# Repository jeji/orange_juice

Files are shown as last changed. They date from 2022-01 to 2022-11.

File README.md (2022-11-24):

# 我的频道 My Channel 
youtube: https://www.youtube.com/channel/UChTFW-Y9eg54AaTY_yama7A \
bilibili：https://b23.tv/pqzW2up

# 版本信息 Release Note
2022/10/09: v0.8 Reverse the polarity to match the common wire setup \
2022/02/06: v0.7 bate release version, passed function and stable test

**[香橙派Zero2版本](https://github.com/jeji/orange_juice_2)** \
**[Version for Orange Pi Zero2](https://github.com/jeji/orange_juice_2)** \

TODO:
- Integrate CAN controller/receivier
- Add motor driver socket as an universal socket for other feature, like: 
   - PWM controlled open loop buck convert for better fan noise 
   - Voron design MAX31865
   - Other SPI/UART/GPIO device

# 开始之前 Before You Start 
- 我并不是专业的电子工程师，设计本项目只是为了好玩和方便DIY Voron 3D打印机
- 你将自行承担由此带来的所有风险
- 社区有诸多反馈香橙派zero的CPU温度过高，所以在使用中请加强散热
- 本项目为基于GPL3.0的开源项目，欢迎魔改。如果你有更好的改进也请务必与我分享 
- **(!) 请特别注意文章中加粗和带"(!)"部分的内容**

- I'm not prefesstional electronic engineer, I designed this for fun and convenience while DIY my Voron printer
- You will take it as your own risk for any potential damages
- Overheat issue is being reported for OrangePi Zero H2+ CPU, hence a proper cooling fan even with cooling fin is strongly recommended
- This project is based GPL3.0 license, you are free to modify it to yourown version. Please do share the joy with me if you did that
- **(!) Please pay attention for the bold and with "(!)" content**

# 代号：橙汁 BoardName：Orange Juice

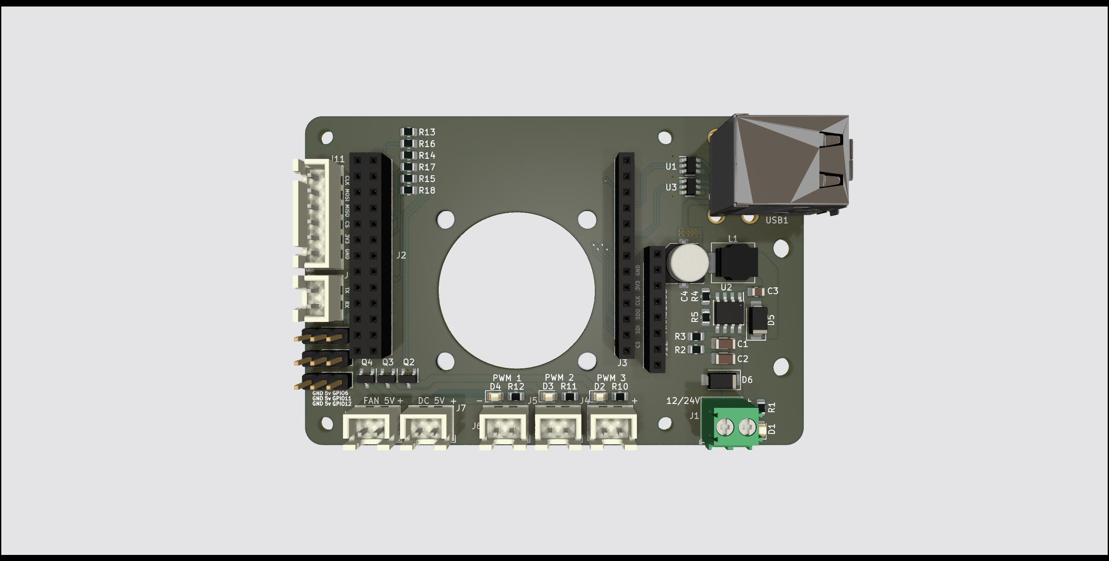
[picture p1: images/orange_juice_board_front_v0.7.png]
  

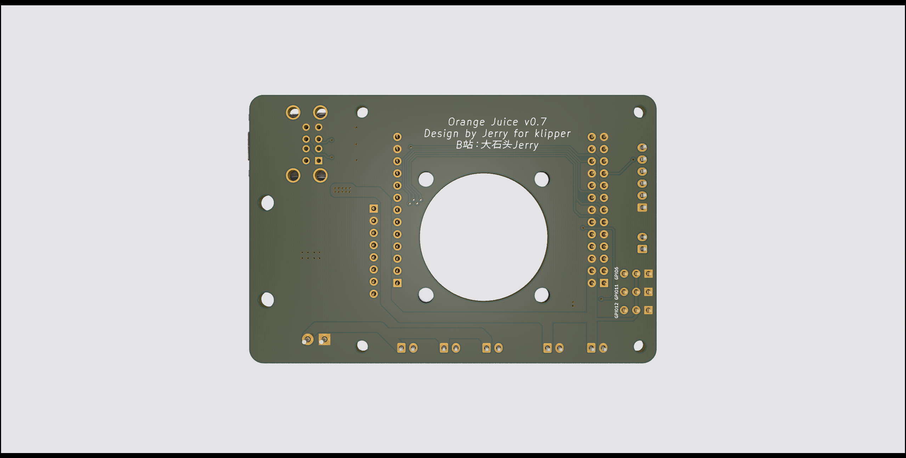
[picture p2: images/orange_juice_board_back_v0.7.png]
  

受全球芯片短缺情况影响，树莓派价格涨到了离谱的位置。
所以香橙派zero成了一个很好的替代品。120元左右的512MB版本可以满足做为klipper宿主的所有需求，甚至有点性能过剩。

klipper有诸多独特的功能需要使用到gpio针脚，每次都用排母端子去连接非常的不方便。在使用扩展板后不仅方便了许多，且可以得到额外的功能：
- 一个专为[ADXL345](https://www.adafruit.com/product/1231) 设计的接口将香橙派SPI1总线引出
- 一个专为[Adafruit MAX31865 board](https://www.adafruit.com/product/3328) 及其克隆版本设计的接口，作为软SPI使用了4个gpio接口
- 两个从香橙派引出的USB2.0 TypeA接口
- 一个UART接口
- 三组gpio控制的PWM输出接口，最大输出电压与输入电压相同
- 三组gpio接口配合5v电源接口，方便自定义其他功能
- 两组恒定5v输出接口
- 一个香橙派专用散热3010风扇安装位
- 自带降压电路，接受9~24V输入电压降压为5V供香橙派及其接口使用
- 扩展板大小及安装孔位与树莓派B系列保持一致
- 使用0805或更大尺寸封装贴片封装以方便手工贴片

Due to current chipset shortage sitatuion, raspberry pi price increase to an unreasonable level. 
Hence OrangePi Zero become a good alternative. A 25 dollars 512MB ram version meets all the requirments I need as a klipper host for my Voron V0.1, and actually even little bit over kill. 

Klipper has some advance features which need connect to gpio pins, it's not that convenience to use a pin header to connect gpio pin every time. Instead of that, with this board, it provides easier connection and more useful features:
- A dedicate [ADXL345](https://www.adafruit.com/product/1231) port is extended from OrangePi zero SPI1 bus
- A dedicate MAX31865 port connect to 4 gpio pins as a SW SPI connection, for [Adafruit MAX31865 board](https://www.adafruit.com/product/3328) or its clone
- Two USB2.0 Type A ports are extended from orange pi function pin
- A UART port for UART communication with printer MCU board
- Three klipper controllable pwm output ports, voltage depends on input DC voltage
- Three gpio port from orangepi with 5v power, for custom function
- Two 5v output ports
- A built-in 3010 chip cooling fan position
- A built-in step-down buck converter to convert DC 9~24v input to DC 5v to supply pi and 5v output socket
- Raspberry Pi B Serials board size and mount hole position compatible 
- 0805 or larger size SMD components are being used for hand soldering

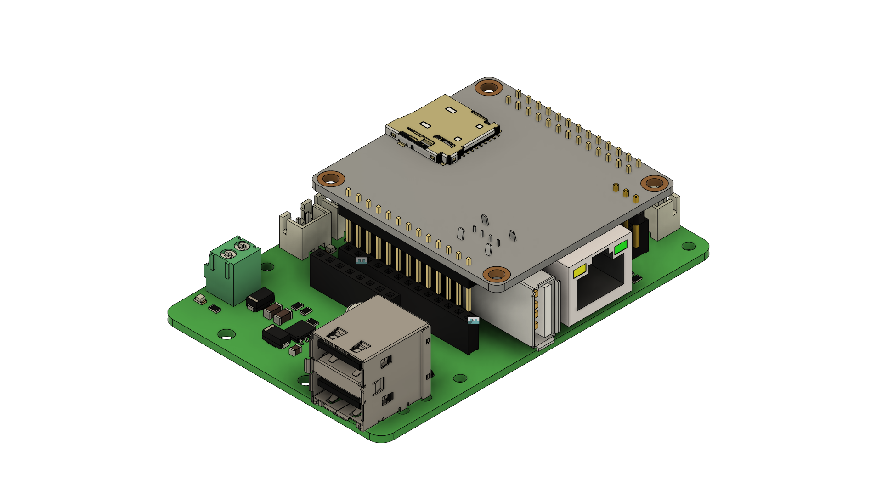
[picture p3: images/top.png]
  

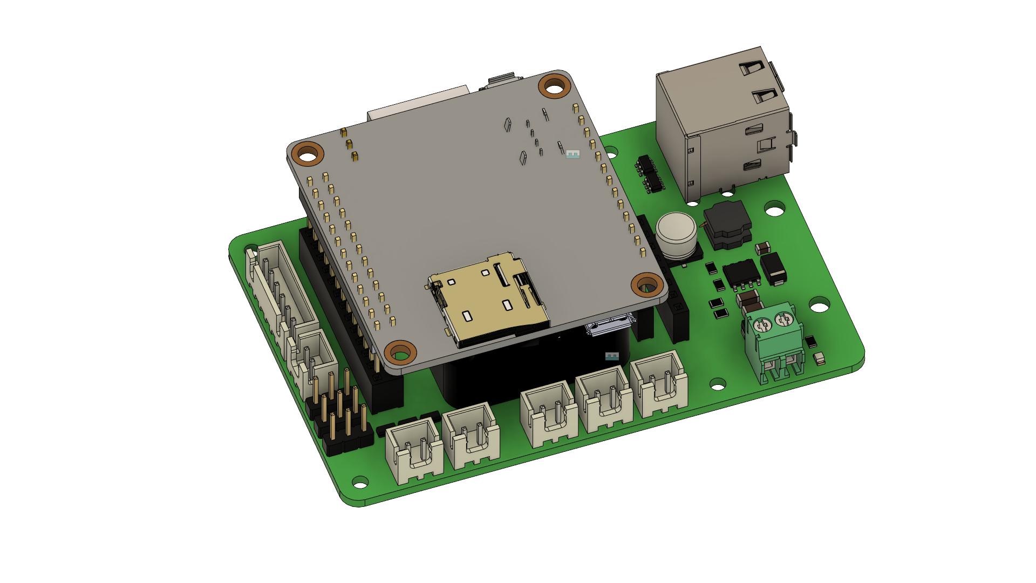
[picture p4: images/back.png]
  

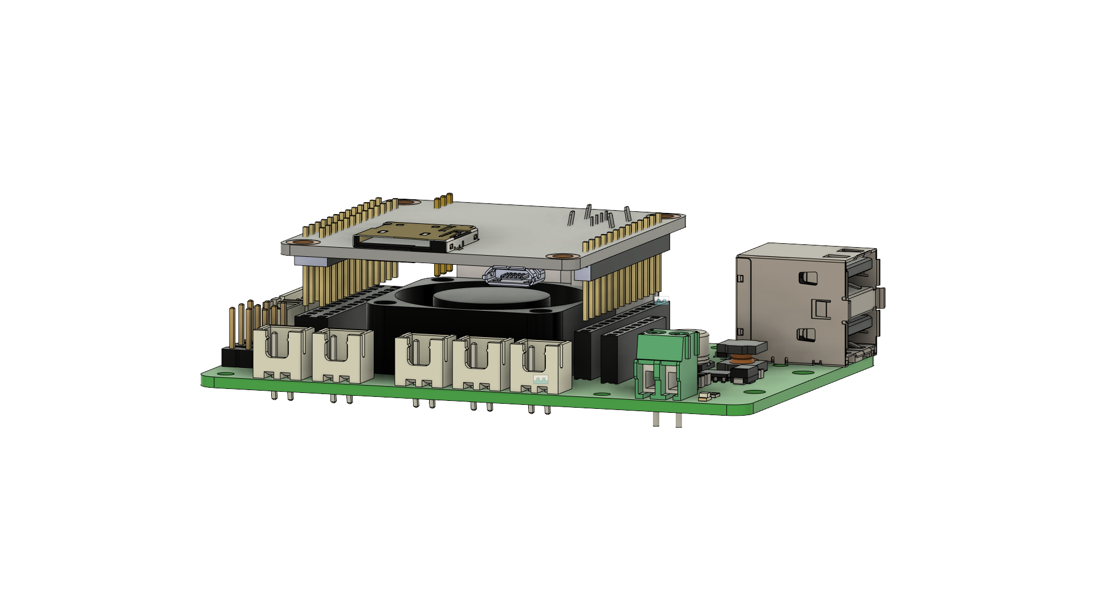
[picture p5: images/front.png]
  

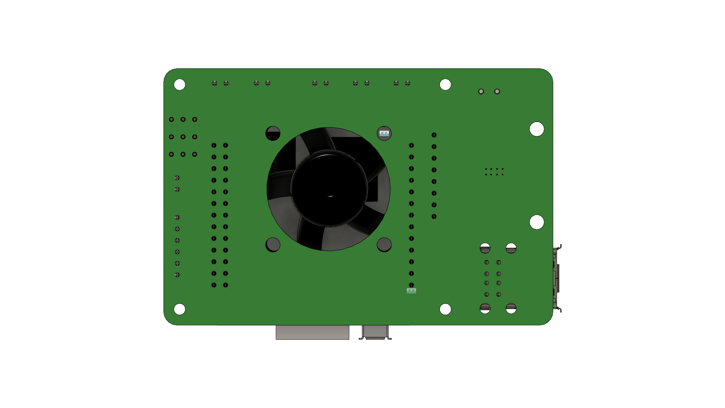
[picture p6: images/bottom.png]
  

# 如何使用 How to use
## 硬件 Hardware
PCB打板：[gerber文件](gerber/orange_juice_v0.8_gerber.zip)
- 你可以在嘉立创或者其他你喜欢的厂商免费打板
- 保持打板厂商默认设置即可

BOM：[电子元件BOM](bom/ibom.html)
- 在立创商城使用BOM单里lcsc part编号搜索即可找到对应原件型号
- 我使用的元件购买至淘宝，主要来自优信
- **(!) 香橙派针脚接头需要使用加高7.5mm的排母针脚，** 参考链接：[这里](https://item.taobao.com/item.htm?spm=a1z09.2.0.0.5abe2e8dp4SvIq&id=562698441144&_u=u181c59936e) 

PCB board：[gerber file](gerber/orange_juice_v0.8_gerber.zip)
- You can get the PCB board from JLC or other PCB manufactory 
- Usually, keep the defualt setting shall be ok when you place your order

BOM：[iBOM](bom/ibom.html)
- Search the component at [LCSC](https://lcsc.com/) via lcsc part number in the BOM
- I got my component from my trust taobao.com shop due to more reasble price 
- **(!) You need the famale pin head with 7.5mm extra feet height for orange pi,** reference link: [Here](https://item.taobao.com/item.htm?spm=a1z09.2.0.0.5abe2e8dp4SvIq&id=562698441144&_u=u181c59936e) 

## 软件 Software

请参考config目录下的orange_juice.cfg文件 \
orange_juice.cfg under config folder for you reference 

**(!) 以下配置依赖香橙派已经被正确配置成klipper客户端，并且香橙派配置名为"opi"** \
具体方法请参考 https://www.klipper3d.org/RPi_microcontroller.html \
**(!) Following configuration is assuming that your pi has been config as a klipper client already with name "opi"** \
If not, please refer to  https://www.klipper3d.org/RPi_microcontroller.html 

ADXL345配置 \
ADXL345 configuration 

```
[adxl345]
cs_pin: opi:gpio13
spi_bus: spidev1.0

[resonance_tester]
accel_chip: adxl345
probe_points: 60,60,20 #测试点，需要更改为你机器热床中心点，依次为x,y,z
```

MAX31865配置如下，**(!) 你还需要在本节或者其他文件里定义挤出机其他配置** \
MAX31865 config, **(!) you have to define other extruder value seperately** 

```
[extruder]
sensor_type: MAX31865
sensor_pin: opi:gpio1
spi_software_sclk_pin: opi:gpio2
spi_software_mosi_pin: opi:gpio0
spi_software_miso_pin: opi:gpio3
rtd_nominal_r: 100
rtd_reference_r: 430
rtd_num_of_wires: 2
rtd_use_50Hz_filter: True
```

PWM接口配置 \
PWM Port configuration

下为PWM控制的输出插座，对应插槽PWM1 ~ PWM3 \
**(!) 请注意，由于香橙派内核原因，PWM2和PWM3从系统加电启动到klipper正式运行前，默认为高电平，即为打开状态。待klipper正式运行后恢复设置状态** \
PWM control input-voltage output slot \
**(!) Pay attention, because of the linux kernel complied by Orange Pi, the PMW2 and PWM3 is on HIGH (ON) from the power on till klipper start functioning**
```
[fan_generic PWM1_Fan]
pin: opi:gpio10
max_power: 1
shutdown_speed: 0
cycle_time: 0.01
#hardware_pwm:
kick_start_time: 0.5
off_below: 0.1
#enable_pin:
#   See the "fan" section for a description of the above parameters.

[fan_generic PWM2_Fan]
pin: opi:gpio18
max_power: 1
shutdown_speed: 0
cycle_time: 0.01
#hardware_pwm:
kick_start_time: 0.5
off_below: 0.1
#enable_pin:
#   See the "fan" section for a description of the above parameters.

[fan_generic PWM3_Fan]
pin: opi:gpio19
max_power: 1
shutdown_speed: 0
cycle_time: 0.01
#hardware_pwm:
kick_start_time: 0.5
off_below: 0.1
#enable_pin:
#   See the "fan" section for a description of the above parameters.
```

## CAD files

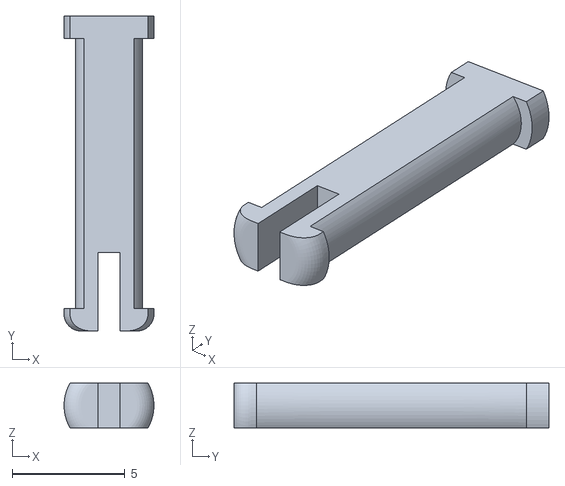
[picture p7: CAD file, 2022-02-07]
STL/3010 Fan Latch x4.stl
4.00 x 14.0 x 2.00

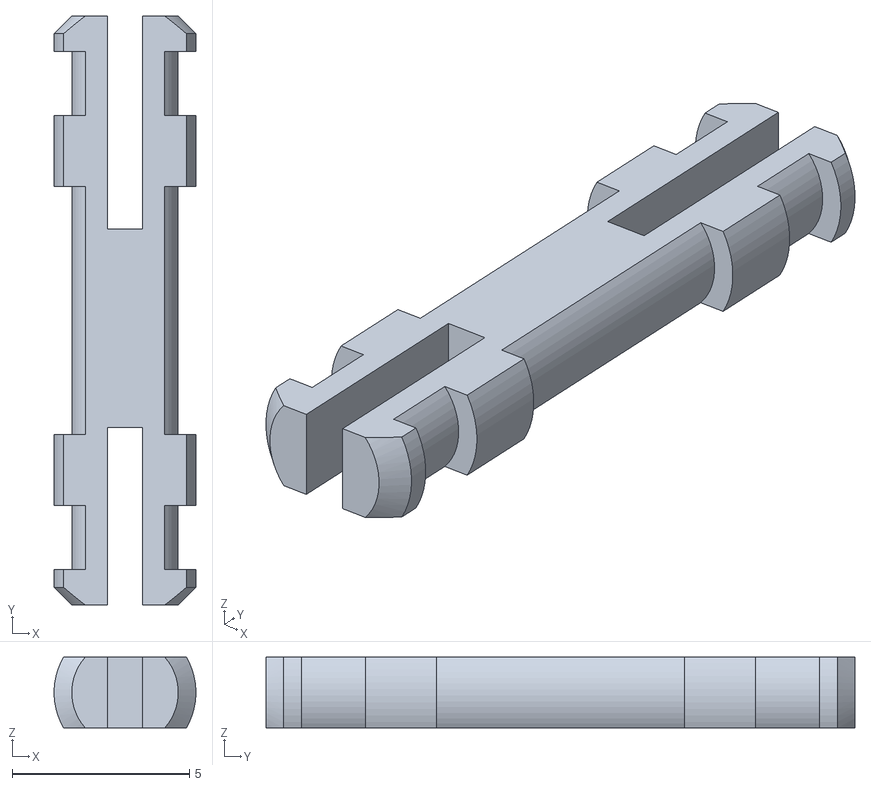
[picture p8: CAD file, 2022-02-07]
STL/MAX31865 Latch x2.stl
4.00 x 16.6 x 2.00

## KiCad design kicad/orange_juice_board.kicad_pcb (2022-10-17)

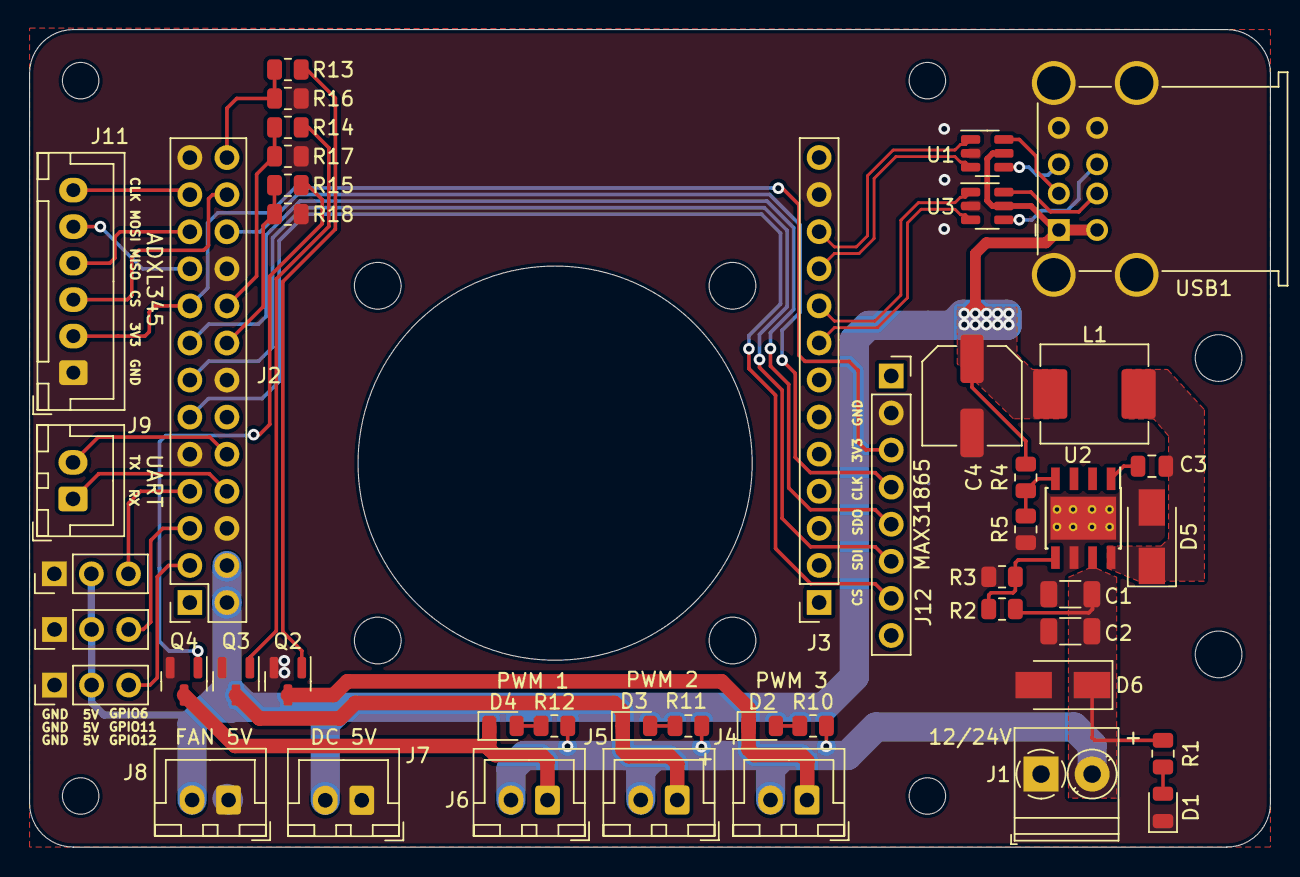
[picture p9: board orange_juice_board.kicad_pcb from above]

Board: 2 copper layers, 85.0 x 56.0 mm, 52 parts (0 on the bottom side), 42 nets.

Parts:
C1, C2: 10uF; C_1206_3216Metric
C3: 10nF; C_0805_2012Metric
C4: 220uF; C_Elec_6.3x5.4
D2: PWM1_STATUS; LED_0805_2012Metric
D3, D3#2: PWM2_STATUS; LED_0805_2012Metric
D4: PWM3_STATUS; LED_0805_2012Metric
D5: B340A; D_SMA
D6: SMAJ24A; D_SMA
H5, H6, H7, H8: MH_FAN; MountingHole_3.2mm_M3
H9, H10: MH_MAX31865; MountingHole_3.2mm_M3
J2: DC_INPUT; TerminalBlock_Phoenix_PT-1,5-2-3.5-H_1x02_P3.50mm_Horizontal
J3: CONN_ADXL345; JST_XH_B6B-XH-A_1x06_P2.50mm_Vertical
J4: OrangePi Zero GPIO PINs; PinSocket_2x13_P2.54mm_Vertical
J7: OrangePi Zero Function Interface; PinSocket_1x13_P2.54mm_Vertical
J8: FAN_5v; JST_XH_B2B-XH-A_1x02_P2.50mm_Vertical
J9: PWR_5v; JST_XH_B2B-XH-A_1x02_P2.50mm_Vertical
J10: GPIO12_Head; PinHeader_1x03_P2.54mm_Vertical
J10#2: PWM_OUT1; JST_XH_B2B-XH-A_1x02_P2.50mm_Vertical
J11: CONN_UART; JST_XH_B2B-XH-A_1x02_P2.50mm_Vertical
J12: PWM_OUT2; JST_XH_B2B-XH-A_1x02_P2.50mm_Vertical
J12#2: Conn_01x08; PinSocket_1x08_P2.54mm_Vertical
J13: GPIO6_Head; PinHeader_1x03_P2.54mm_Vertical
J14: GPIO11_Head; PinHeader_1x03_P2.54mm_Vertical
J15: PWM_OUT3; JST_XH_B2B-XH-A_1x02_P2.50mm_Vertical
L1: 22uH; L_Abracon_ASPI-0630LR
Q2, Q3, Q4: AO3400A; SOT-23
R2: 100K; R_0805_2012Metric
R3: 25K5; R_0805_2012Metric
R4: 10K; R_0805_2012Metric
R4#2, R7, R7#2, R10: 4k7; R_0805_2012Metric
R5, R8, R14: 100; R_0805_2012Metric
R5#2: 3.24K; R_0805_2012Metric
R6, R9, R15: 10k; R_0805_2012Metric
U1, U3: USBLC6-2SC6; SOT-23-6
U2: TPS5430DDA; TI_SO-PowerPAD-8_ThermalVias
USB1: USB_A_Port_x2; USB_A_Wuerth_61400826021_Horizontal_Stacked

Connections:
BUCK_BOOT: C3.2, U2.1 (BOOT)
BUCK_EN: R2.2, R3.1, U2.5 (EN)
BUCK_IN: C1.1, C2.1, D6.1 (A1), J2.2, J10#2.2, J12.2, J15.2, R2.1, R4#2.2, R7.1, R7#2.2, R10.2, U2.7 (VIN)
BUCK_OUT: C4.1, J4.2, J4.4, J8.2, J9.2, J10.2, J13.2, J14.2, L1.2, R4.1, U1.5 (VBUS), U3.5 (VBUS), USB1.1 (VCC), USB1.5 (VCC)
BUCK_PH: C3.1, D5.1 (K), L1.1, U2.8 (PH)
BUCK_VSNS: R4.2, R5#2.1, U2.4 (VSENSE)
GND: C1.2, C2.2, C4.2, D3#2.1 (K), D5.2 (A), D6.2 (A2), J2.1, J3.1, J4.6, J4.9, J4.14, J4.20, J4.25, J7.12, J8.1, J9.1, J10.1, J12#2.2, J13.1, J14.1, Q2.2 (S), Q3.2 (S), Q4.2 (S), R3.2, R5#2.2, R6.1, R9.1, R15.1, U1.2 (GND), U2.6 (GND), U2.9 (GNDPAD), U3.2 (GND), USB1.4 (GND), USB1.8 (GND), USB1.9 (Shield)
GPIO6: J4.7, J13.3
GPIO11: J4.5, J14.3
GPIO12: J4.3, J10.3
GPIO_0_SDI: J4.13, J12#2.6
GPIO_1_CS: J4.11, J12#2.7
GPIO_2_CLK: J4.22, J12#2.4
GPIO_3_SDO: J4.15, J12#2.5
GPIO_10: J4.26, R5.2, R6.2
GPIO_18: J4.18, R8.2, R9.2
GPIO_19: J4.16, R14.2, R15.2
unnamed: D3#2.2 (A), R7.2
unnamed: D2.1 (K), J10#2.1, Q2.3 (D)
unnamed: D2.2 (A), R4#2.1
unnamed: D3.1 (K), J12.1, Q3.3 (D)
unnamed: D3.2 (A), R7#2.1
unnamed: D4.1 (K), J15.1, Q4.3 (D)
unnamed: D4.2 (A), R10.1
unnamed: Q2.1 (G), R5.1
unnamed: Q3.1 (G), R8.1
unnamed: Q4.1 (G), R14.1
PI_3.3V: J3.2, J4.17, J12#2.3
SPI1_CLK: J3.6, J4.23
SPI1_CS: J3.3, J4.24
SPI1_MISO: J3.4, J4.21
SPI1_MOSI: J3.5, J4.19
UART1_RX: J4.10, J11.2
UART1_TX: J4.8, J11.1
USB2_Conn_D+: U1.4 (I/O2), USB1.3 (D+)
USB2_Conn_D-: U1.6 (I/O1), USB1.2 (D-)
USB2_D+: J7.10, U1.3 (I/O2)
USB2_D-: J7.11, U1.1 (I/O1)
USB3_Conn_D+: U3.4 (I/O2), USB1.7 (D+)
USB3_Conn_D-: U3.6 (I/O1), USB1.6 (D-)
USB3_D+: J7.8, U3.3 (I/O2)
USB3_D-: J7.9, U3.1 (I/O1)

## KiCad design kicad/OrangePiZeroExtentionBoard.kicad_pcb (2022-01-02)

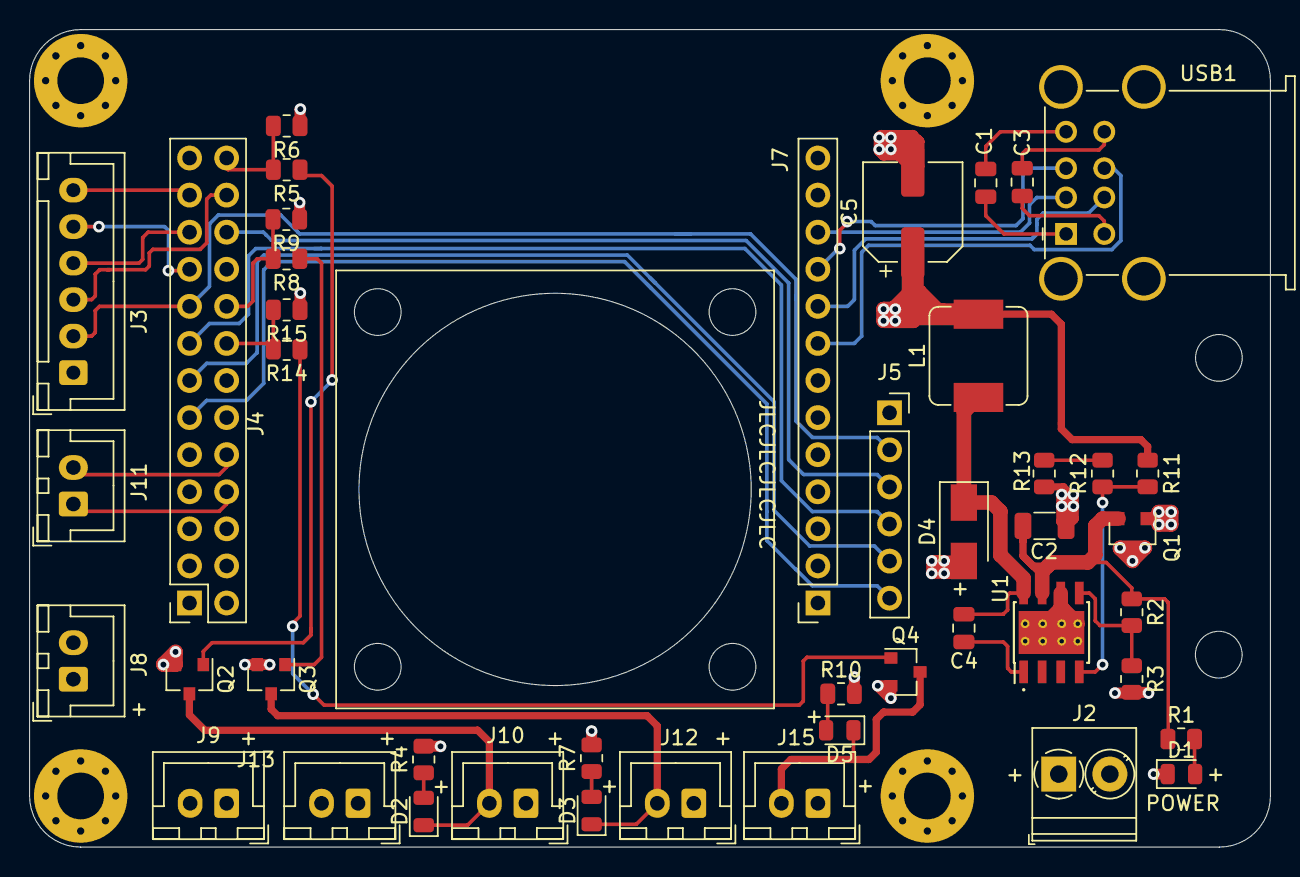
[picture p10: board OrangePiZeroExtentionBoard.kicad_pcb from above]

Board: 4 copper layers, 85.0 x 56.0 mm, 54 parts (0 on the bottom side), 37 nets.

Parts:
C1, C3: 22u; C_0805_2012Metric
C2: 10u; C_1206_3216Metric
C4: 10n; C_0805_2012Metric
C5: 220u; CP_Elec_6.3x5.4
D1: PWR_LED; LED_0805_2012Metric
D2: PWM1_STATUS; LED_0805_2012Metric
D3: PWM2_STATUS; LED_0805_2012Metric
D4: B340A; D_SMA
D5: PWM3_STATUS; LED_0805_2012Metric
H1, H2, H3, H4: MH_Board; MountingHole_3.2mm_M3_Pad_Via
H5, H6, H7, H8: MH_FAN; MountingHole_3.2mm_M3
H9, H10: MH_MAX31865; MountingHole_3.2mm_M3
J2: DC_INPUT; TerminalBlock_Phoenix_PT-1,5-2-3.5-H_1x02_P3.50mm_Horizontal
J3: CONN_ADXL345; JST_XH_B6B-XH-A_1x06_P2.50mm_Vertical
J4: OrangePi Zero GPIO PINs; PinSocket_2x13_P2.54mm_Vertical
J5: Conn_MAX31865; PinSocket_1x06_P2.54mm_Vertical
J7: OrangePi Zero Function Interface; PinSocket_1x13_P2.54mm_Vertical
J8: FAN_5v; JST_XH_B2B-XH-A_1x02_P2.50mm_Vertical
J9: PWR_5v; JST_XH_B2B-XH-A_1x02_P2.50mm_Vertical
J10: PWM_OUT1; JST_XH_B2B-XH-A_1x02_P2.50mm_Vertical
J11: CONN_UART; JST_XH_B2B-XH-A_1x02_P2.50mm_Vertical
J12: PWM_OUT2; JST_XH_B2B-XH-A_1x02_P2.50mm_Vertical
J13: FAN_12/24v; JST_XH_B2B-XH-A_1x02_P2.50mm_Vertical
J15: PWM_OUT3; JST_XH_B2B-XH-A_1x02_P2.50mm_Vertical
L1: 15u; L_Sumida_CDMC6D28_7.25x6.5mm
Q1: AO3401A; SOT-23
Q2, Q3, Q4: AO3400A; SOT-23
R1, R4, R7, R10: 4k7; R_0805_2012Metric
R2: 100k; R_0805_2012Metric
R3: 21k; R_0805_2012Metric
R5, R8, R14: 100; R_0805_2012Metric
R6, R9, R11, R15: 10k; R_0805_2012Metric
R12: 3k; R_0805_2012Metric
R13: 240; R_0805_2012Metric
U1: TPS5430; TI_SO-PowerPAD-8_ThermalVias
USB1: USB_A_Port_x2; USB_A_Wuerth_61400826021_Horizontal_Stacked

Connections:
+3V3: J3.2, J4.17, J5.2
+5V: C1.1, C3.1, C5.1, J4.2, J4.4, J7.13, J8.1, J9.1, L1.2, R11.1, USB1.1, USB1.5
BUCK_BOOT: C4.1, U1.1
BUCK_EN: R2.2, R3.1, U1.5
BUCK_IN: C2.1, Q1.2, R1.1, R2.1, U1.7
BUCK_PH: C4.2, D4.1, L1.1, U1.8
BUCK_VSNS: R11.2, R12.1, U1.4
DCIN: J2.1, J10.1, J12.1, J13.1, J15.1, Q1.3, R4.2, R7.2, R10.2
GND: C1.2, C2.2, C3.2, C5.2, D1.1, D4.2, J2.2, J3.1, J4.6, J4.9, J4.14, J4.20, J4.25, J5.1, J7.12, J8.2, J9.2, J13.2, Q1.1, Q2.2, Q3.2, Q4.2, R3.2, R6.1, R9.1, R13.2, R15.1, U1.6, U1.9, USB1.4, USB1.8
GPIO_0_SDI: J4.13, J5.5
GPIO_1_CS: J4.11, J5.6
GPIO_2_CLK: J4.22, J5.3
GPIO_3_SDO: J4.15, J5.4
GPIO_10: J4.26, R5.2, R6.2
GPIO_18: J4.18, R8.2, R9.2
GPIO_19: J4.16, R14.2, R15.2
unnamed: D1.2, R1.2
unnamed: D2.1, J10.2, Q2.3
unnamed: D2.2, R4.1
unnamed: D3.1, J12.2, Q3.3
unnamed: D3.2, R7.1
unnamed: D5.1, J15.2, Q4.3
unnamed: D5.2, R10.1
unnamed: Q2.1, R5.1
unnamed: Q3.1, R8.1
unnamed: Q4.1, R14.1
unnamed: R12.2, R13.1
SPI1_CLK: J3.6, J4.23
SPI1_CS: J3.3, J4.24
SPI1_MISO: J3.4, J4.21
SPI1_MOSI: J3.5, J4.19
UART1_RX: J4.8, J11.1
UART1_TX: J4.10, J11.2
USB_DM2: J7.11, USB1.2
USB_DM3: J7.9, USB1.6
USB_DP2: J7.10, USB1.3
USB_DP3: J7.8, USB1.7

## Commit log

2021-12-28 initial upload
    [OrangePiZeroExtentionBoard-B_Cu.gbr, OrangePiZeroExtentionBoard-B_Mask.gbr, OrangePiZeroExtentionBoard-B_Paste.gbr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]
2021-12-28 update pin head footprint
    [OrangePiZeroExtentionBoard.kicad_pcb, OrangePiZeroExtentionBoard.sch]
2022-01-01 update bom
    [lcsc_bom.csv]
2022-01-02 update details
    [OrangePiZeroExtentionBoard.kicad_pcb]
2022-01-04 update kicad files
    [orange_juice_board.kicad_pcb]
2022-01-05 update gerber
    [OrangePiZeroExtentionBoard-B_Cu.gbr, OrangePiZeroExtentionBoard-F_Cu.gbr, OrangePiZeroExtentionBoard-NPTH.drl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]
2022-01-09 version 0.3
    [orange_juice_board.kicad_pcb, orange_juice_board.kicad_sch, orange_juice_board.sch]
2022-01-09 update version 0.3
    [orange_juice_board-B_Cu.gbr, orange_juice_board-B_Mask.gbr, orange_juice_board-B_Paste.gbr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]
2022-01-16 bate version
    [IND_222NLT_PUL.step, orange_juice_board - 副本.kicad_pcb, orange_juice_board.kicad_pcb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]
2022-01-24 update to v0.6
    [orange_juice_board.kicad_pcb, orange_juice_board.kicad_sch]
2022-01-30 Official v0.6 release
    [orange_juice_board-B_Cu.gbr, orange_juice_board-B_Mask.gbr, orange_juice_board-B_Paste.gbr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]
2022-02-04 update to v0.7
    [orange_juice_board-B_Cu.gbr, orange_juice_board-B_Mask.gbr, orange_juice_board-B_Paste.gbr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]
2022-02-06 minor update
    [orange_juice_board-B_Cu.gbr, orange_juice_board-B_Mask.gbr, orange_juice_board-B_Paste.gbr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]
2022-10-09 Update readme and config
    Update readme with sw config example
    [orange_juice.cfg]
2022-10-09 Reverse polarity
    [orange_juice_board.kicad_sch]
2022-10-09 v0.8 Update
    reverse the polarity
    [orange_juice_board-B_Cu.gbr, orange_juice_board-B_Mask.gbr, orange_juice_board-B_Paste.gbr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]
2022-10-15 Update front silk text
    [orange_juice_board.kicad_pcb]
2022-10-17 Update front silk symbol
    Correct the power socket symbol
    [orange_juice_board-B_Cu.gbr, orange_juice_board-B_Mask.gbr, orange_juice_board-B_Paste.gbr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]
